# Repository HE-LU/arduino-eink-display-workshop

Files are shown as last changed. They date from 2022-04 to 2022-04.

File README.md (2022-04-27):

# Kundolap Workshop

Everyone was in the situation when he need to attract some female of the species. For this purpose, you can build your own **Kundolap**. It is light and small, so you can take it anywhere with you. Just press the button and wait.

<p align="center">
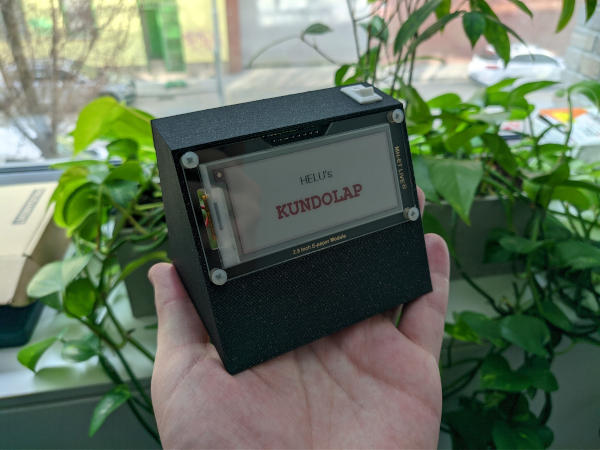
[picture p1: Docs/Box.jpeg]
  
</p>

The program connects to Wi-Fi, loads JSON data from Google Spreadsheets API, parses the JSON, and displays the data on the screen. ESP8266 board periodically goes to deep sleep to save the battery.

## Hardware Components
- **1x** NodeMCU V3(CH340G) board with ESP8266 Microchip - **2.39$**
- **1x** MH-ET LIVE 2.9' E-Paper Module(Red) - **19.26$**
- **1x** TP4056 USB-C Lithium Battery Charger Module - **0.44$**
- **1x** LiitoKala 18650 HG2 3000 mAh Li-Ion Battery - **6.35$**
- **1x** Push Button Switch 10 x 15 mm - **0.15$**
- Some cables, soldering wire. **0.1$**
- Plastic box printed on Prusa 3D printer

**Total price: 28.69$**

Some components can be much cheaper when bought in bulk.

## Hardware Connections
- Connection of TP4056 module, NodeMCU board, button switch, battery:
  - TP4056.OUT+ -> Button 0
  - TP4056.B+ -> Battery +
  - TP4056.B- -> Battery -
  - TP4056.OUT- -> NodeMCU.G
  - NodeMCU.VIN -> Button 1

- Connection of E-Paper module with NodeMCU board:
  - BUSY -> D2
  - RST -> D4
  - DC -> D3
  - CS -> D8
  - SCLK -> D5
  - SDI -> D7
  - GND -> GND
  - VCC -> 3V

- NodeMCU board connections:
  - D0 -> RST for the deep sleep (disconnect when programming)
  - 3K3 pull-down resistor between D8 and GND

## IDE Setup
- Install **CH340** driver
- Install **Arduino IDE**
- Install **ESP8266** add-on in Arduino IDE
  - File -> Preferences
  - Add additional boards manager URL: http://arduino.esp8266.com/stable/package_esp8266com_index.json
  - Tools -> Board -> Boards Manager
  - Search for **ESP8266** and press install button for the “ESP8266 by ESP8266 Community“
  - Select the board in Tools -> Boards -> ESP8266 Boards -> **NodeMCU 1.0 (ESP-12E Module)** (You may need to restart the IDE first)
- Install libraries in Arduino IDE
  - Tools -> Manage Libraries
  - Search and install **GxEPD2**, **ArduinoJson** and **Adafruit BusIO**
- Tools -> Upload Speed -> 921600
- You will need to select correct USB port (Tools -> Port)

### Advanced IDE Setup
1. Download VSCode if you don't have it already
2. Install "Arduino" Plugin (Arduino for Visual Studio Code) - In extensions tab on the left - box icon, Shift+Cmd+X
3. Open project folder
4. When popup with C++ support appear, feel free to install it
5. When popup "Configure your IntelliSense settings to help find missing headers" appears, you can hit skip, or close it.
6. Enter View -> Command Pallete(Ctrl + Shift + P or Cmd + Shift + P) and run `Arduino: Initialize`
7. You will be asked to select baord type. You should select following one: `NodeMCU 1.0(ESP-12E Module)`
8. Delete file in `.vscode/c_cpp_properties.json` and restart VSCode.
9. Wait and hope that all files will be correctly initialized and all warning disappear.

Note: In any case, you can try to also follow any tutorial like this one: https://maker.pro/arduino/tutorial/how-to-use-visual-studio-code-for-arduino

## Power Consumption
The power consumption of the whole device is still not ideal. The main problem is that there are two voltage converters used. We should focus on this more in the future. Right now we have one step-up convertor to make 5V from the battery. NodeMCU then takes this 5V and uses a step-down convertor to make 3.3V out of it. This leads to much bigger power consumption than needed.

So far I measured the following power consumption:
- 3.8 mA when the device is in Deep Sleep. ESP8266 should have around 20µA in the deep sleep. You can nicely see the voltage regulator problem here.
- 70 mA when under heavy load with WiFi on.
- 25 mA when the display is refreshing.

## Developed by
[Lukas Hermann](https://helu.cz/)
[Petr Nohejl](https://petrnohejl.cz)

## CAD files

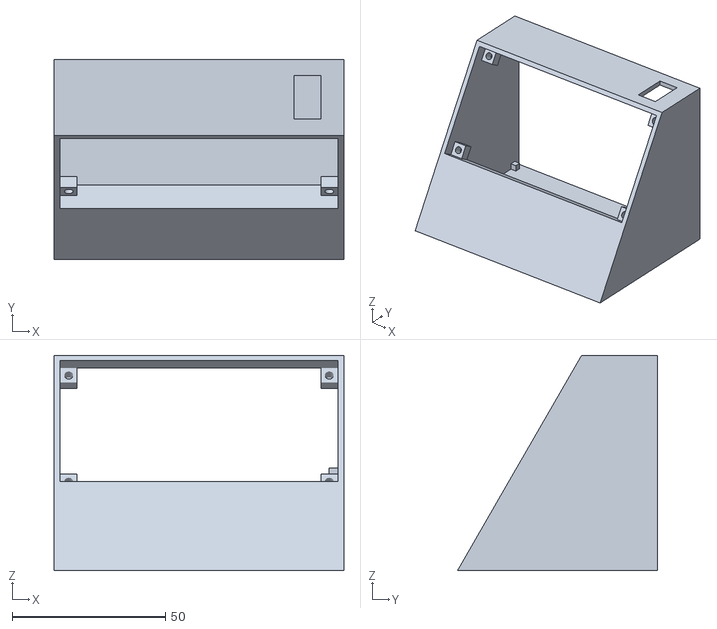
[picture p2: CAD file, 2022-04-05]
Box 3D Model/ArduinoBoxWithHoles.stl
94.6 x 65.3 x 70.2

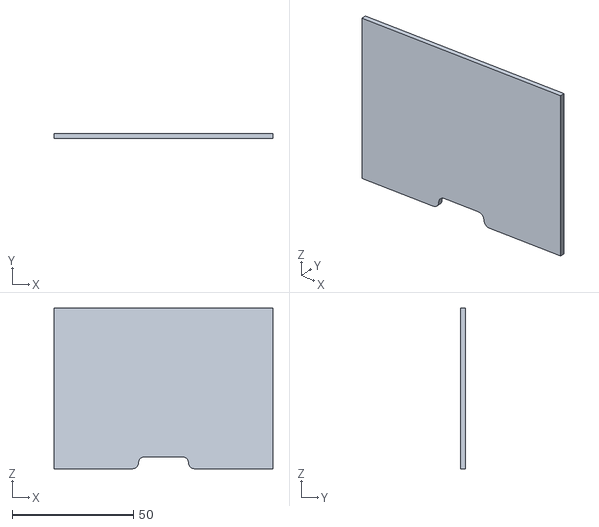
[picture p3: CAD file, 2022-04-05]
Box 3D Model/ArduinoBoxWithHoles-Back.stl
90.4 x 2.00 x 66.3

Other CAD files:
Box 3D Model/ArduinoBox.blend

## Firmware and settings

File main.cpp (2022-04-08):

#include <ESP8266HTTPClient.h>
#include <ESP8266WiFi.h>
#include <GxEPD2_3C.h>
#include <GxEPD2_BW.h>
#include <Fonts/FreeSerif9pt7b.h> // fonts: https://github.com/adafruit/Adafruit-GFX-Library/tree/master/Fonts

#include "main.h"
#include "display.h"
#include "wifi.h"
#include "examples.h"

const String SPREADSHEET_URL = "https://sheets.googleapis.com/v4/spreadsheets/XXXXXXXXXXXXXXXXXXXXXXXXXXXXXXXXXXXXXXXXX/values/"
							   "Arduino?alt=json&valueRenderOption=FORMATTED_VALUE&key=XXXXXXXXXXXXXXXXXXXXXXXXXXXXXXXXXXXXXXX";
const String WIFI_SSIDS[ARRAY_SIZE] = {"wifi1", "wifi2"};
const String WIFI_PASSWORDS[ARRAY_SIZE] = {"pass1", "pass2"};

int main()
{
	//connectToWiFi(WIFI_SSIDS[0], WIFI_PASSWORDS[0]);
	connectToMultiWiFi(WIFI_SSIDS, WIFI_PASSWORDS);
	StaticJsonDocument<JSON_BUFFER_SIZE> data = loadData(SPREADSHEET_URL);
	disconnectWiFi();

	DataHolder dataHolder = parseData(data);

	displayData(dataHolder);
	return 0;
}

StaticJsonDocument<JSON_BUFFER_SIZE> loadData(String url)
{
	Serial.println("Loading data from: " + url);

	WiFiClientSecure wifiClient;
	wifiClient.setInsecure();
	wifiClient.connect(url, 80);

	HTTPClient httpClient;
	httpClient.begin(wifiClient, url);

	int httpStatus = httpClient.GET();
	String payload = httpClient.getString();
	httpClient.end();

	Serial.print("HTTP status code: ");
	Serial.println(httpStatus);
	Serial.print("Payload: ");
	Serial.println(payload);

	if(httpStatus == 200)
	{
		StaticJsonDocument<JSON_BUFFER_SIZE> jsonBuffer;
		DeserializationError parseError = deserializeJson(jsonBuffer, payload);

		if(parseError)
		{
			Serial.println("JSON parse error");
		}
		else
		{
			Serial.println("Parsing JSON data success");
			return jsonBuffer;
		}
	}
	else
	{
		Serial.println("HTTP response error");
	}

	return StaticJsonDocument<JSON_BUFFER_SIZE>();
}

DataHolder parseData(StaticJsonDocument<JSON_BUFFER_SIZE>& jsonBuffer)
{
	String header = jsonBuffer["values"][0][0].as<String>();

	String symbol1 = jsonBuffer["values"][1][0].as<String>();
	String value1 = jsonBuffer["values"][1][1].as<String>();
	String change1 = jsonBuffer["values"][1][2].as<String>();
	String item1 = alignText(symbol1, 7, true) + alignText(value1, 7, false) + alignText(change1, 9, false);

	String symbol2 = jsonBuffer["values"][2][0].as<String>();
	String value2 = jsonBuffer["values"][2][1].as<String>();
	String change2 = jsonBuffer["values"][2][2].as<String>();
	String item2 = alignText(symbol2, 7, true) + alignText(value2, 7, false) + alignText(change2, 9, false);

	String symbol3 = jsonBuffer["values"][3][0].as<String>();
	String value3 = jsonBuffer["values"][3][1].as<String>();
	String change3 = jsonBuffer["values"][3][2].as<String>();
	String item3 = alignText(symbol3, 7, true) + alignText(value3, 7, false) + alignText(change3, 9, false);

	String portfolioValue = jsonBuffer["values"][4][0].as<String>();
	String portfolioReturn = jsonBuffer["values"][4][1].as<String>();
	String portfolioGain = jsonBuffer["values"][4][2].as<String>();
	String footer = portfolioValue + "  " + portfolioReturn + "  " + portfolioGain;

	return DataHolder(header, item1, item2, item3, footer);
}

void displayData(DataHolder data)
{
	display.init(115200);
	display.setRotation(3); // landscape
	display.setFullWindow();
	display.firstPage();

	int16_t textBoundsX, textBoundsY;
	uint16_t textBoundsWidth, textBoundsHeight;

	uint16_t displayWidth = display.width() - 1;
	uint16_t displayHeight = display.height() - 1;
	uint16_t paddingHorizontal = 8;
	uint16_t paddingTop = 21;
	uint16_t lineHeight = 24;
	uint16_t linePadding = 4;

	do
	{
		display.fillScreen(GxEPD_WHITE);
		display.setFont(&FreeSerif9pt7b);

		// header text
		display.setTextColor(GxEPD_RED);
		display.getTextBounds(data.header, 0, 0, &textBoundsX, &textBoundsY, &textBoundsWidth, &textBoundsHeight);
		uint16_t headerX = ((display.width() - textBoundsWidth) / 2) - textBoundsX;
		display.setCursor(headerX, paddingTop);
		display.print(data.header);

		// header line
		uint16_t headerLineY = lineHeight + linePadding;
		display.drawLine(paddingHorizontal, headerLineY, displayWidth - paddingHorizontal, headerLineY, GxEPD_RED);

		// text 1
		display.setTextColor(GxEPD_BLACK);
		display.setCursor(paddingHorizontal, paddingTop + lineHeight);
		display.print(data.item1);

		// text 2
		display.setCursor(paddingHorizontal, paddingTop + lineHeight * 2);
		display.print(data.item2);

		// text 3
		display.setCursor(paddingHorizontal, paddingTop + lineHeight * 3);
		display.print(data.item3);

		// footer line
		uint16_t footerLineY = (lineHeight * 4) + linePadding;
		display.drawLine(paddingHorizontal, footerLineY, displayWidth - paddingHorizontal, footerLineY, GxEPD_RED);

		// footer text
		display.setTextColor(GxEPD_RED);
		display.getTextBounds(data.footer, 0, 0, &textBoundsX, &textBoundsY, &textBoundsWidth, &textBoundsHeight);
		uint16_t footerX = ((display.width() - textBoundsWidth) / 2) - textBoundsX;
		display.setCursor(footerX, paddingTop + lineHeight * 4);
		display.print(data.footer);

		// rectangle
		display.drawLine(0, 0, displayWidth, 0, GxEPD_BLACK);
		display.drawLine(0, 0, 0, displayHeight, GxEPD_BLACK);
		display.drawLine(displayWidth, 0, displayWidth, displayHeight, GxEPD_BLACK);
		display.drawLine(0, displayHeight, displayWidth, displayHeight, GxEPD_BLACK);

	} while(display.nextPage());
}

String alignText(String text, int length, bool toLeft)
{
	while(text.length() < length)
	{
		if(toLeft)
		{
			text = text + " ";
		}
		else
		{
			text = " " + text;
		}
	}
	return text;
}

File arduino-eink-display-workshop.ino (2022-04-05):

#include "main.h"

#define DEEP_SLEEP 1 // in minutes
#define BAUD_RATE 57600

// This method is run only once on the device start-up
void setup()
{
	// Init
	uint64_t timestampStart = micros();
	Serial.begin(BAUD_RATE);
	Serial.println();

	// Run Main program
	main();

	// Go into Deep Sleep
	uint64_t timestampEnd = micros();
	uint64_t runtimeLengthMicros = timestampEnd - timestampStart;
	uint64_t deepSleepMicros = DEEP_SLEEP * 60 * 1000 * 1000;
	ESP.deepSleep(deepSleepMicros - runtimeLengthMicros); // x minutes in microseconds
}

// This method is called in a loop
void loop() { }
